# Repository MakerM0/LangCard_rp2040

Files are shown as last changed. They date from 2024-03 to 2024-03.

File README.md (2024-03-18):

# LangCard_rp2040

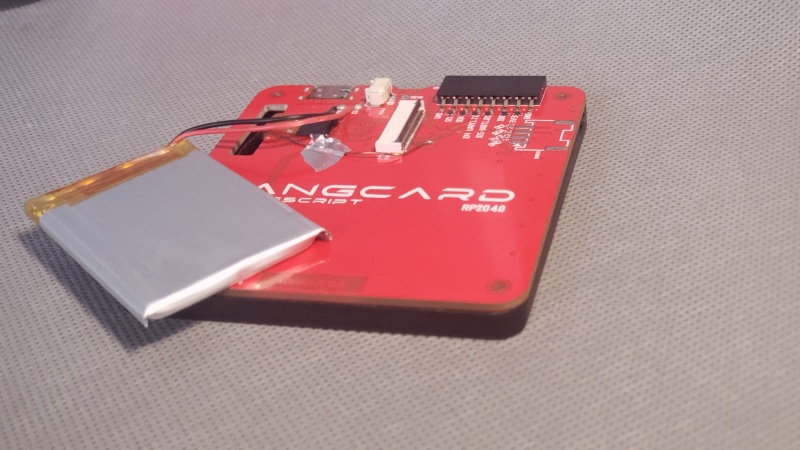
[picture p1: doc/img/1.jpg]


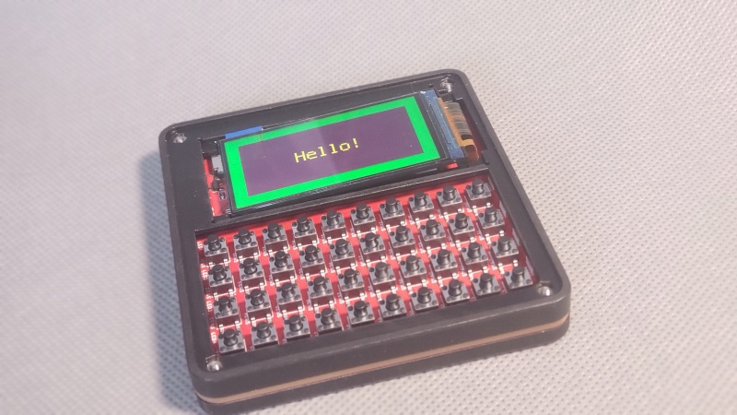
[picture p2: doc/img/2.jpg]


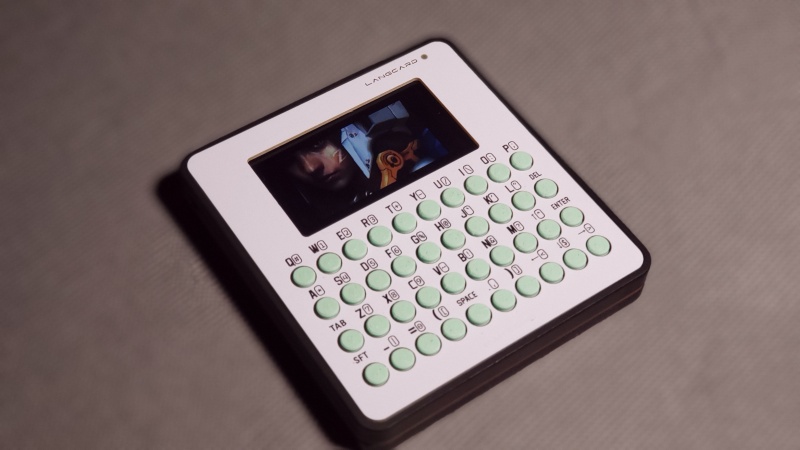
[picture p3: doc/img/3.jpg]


# PCB

The panel is made in the form of a PCB with a thickness of 1.0mm.

The thickness of the motherboard is 1.6mm, and the latest version is  Ver1.2.

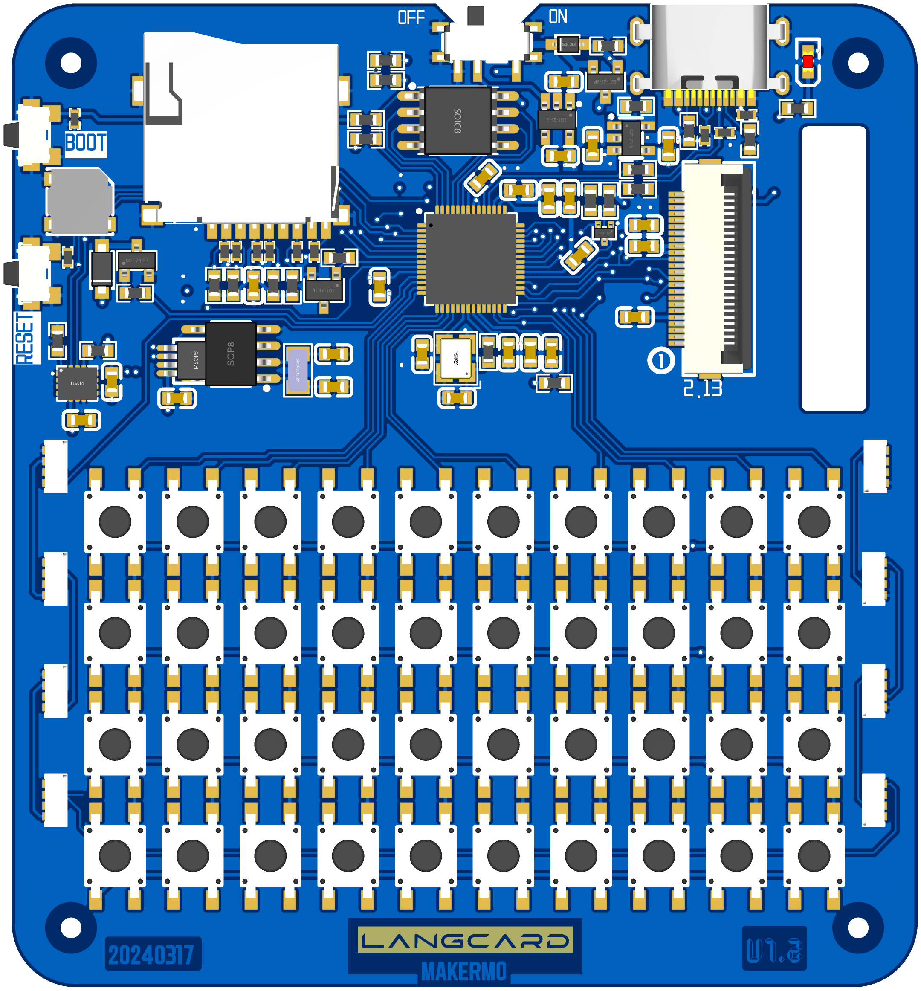
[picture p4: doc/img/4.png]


# Thanks

The [PCBway](https://pcbway.com/g/9CosjL) sponsored the project.

The demos is from:

- [github.com/Bodmer/TFT_eSPI](https://github.com/Bodmer/TFT_eSPI)
- [github.com/lvgl/lvgl](https://github.com/lvgl/lvgl)

- [github.com/VolosR](https://github.com/VolosR)
- [CircuitPython](https://circuitpython.org/)

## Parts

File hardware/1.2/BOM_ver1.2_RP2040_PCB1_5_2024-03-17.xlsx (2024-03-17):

Comment | Designator | Footprint | Supplier Part | Quantity
SMD-5025-0340-12Ω | BUZZER4 | BUZ-SMD_3P-L5.0-W5.0-BL | C2693575 | 1
12pF | C1,C6 | C0603 | C38523 | 2
10uF | C2,C5,C51 | C0603 | C19702 | 3
1uF | C3,C8,C208,C209,C210,C211,C212,C213,C214,C215 | C0603 | C15849 | 10
100nF | C4,C7,C9,C10,C11,C12,C13,C52,C53 | C0603 | C14663 | 9
100nF | C27 | C0603 | C1591 | 1
6pF | C49,C50 | C0603 | C37474 | 2
10uF | C216,C217 | c0603 | C19702 | 2
TF-01A | CARD1 | TF-SMD_TF-02 | C2889258 | 1
1N4148W | D3 | SOD-123F_L2.7-W1.6-LS3.8-RD | C81598 | 1
1N5819WS | D4 | sod-323_l1.8-w1.3-ls2.5-rd | C191023 | 1
PESDNC2FD3V3B | D9,D11,D12,D13,D14,D15,D16,D17,D18,D19,D20,D21,D22,D23,D25 | DFN1006-2L-BI | C492728 | 15
PESDNC2FD5VB | D10 | DFN1006-2L-BI | C110694 | 1
2.13寸电子水墨屏 | FPC2 | FPC-SMD_P0.50-24P_FGS-XJ-H2.0 |  | 1
AFC42-S12FMA-1H | FPC4 | CONN-SMD_12P-P0.50_L3.1-W8.0 | C466532 | 1
1.25-2PWB | FPC6 | CONN-SMD_2P-P1.25_DEALON_1.25-2PWB | C2905009 | 1
XL-4020RGBC-WS2812B | LED1,LED2,LED3,LED4,LED6,LED7,LED8,LED9 | LED-SMD_4P-L4.0-W1.7_M4020-03003-RGB-862-001 | C3647024 | 8
19-217/R6C-AL1M2VY/6T | LED5 | LED0603-R-FD | C2986060 | 1
BSS138 | Q1 | SOT-23-3_L2.9-W1.6-P1.90-LS2.8-BR | C112239 | 1
SS8050 | Q202 | SOT-23-3_L2.9-W1.3-P1.90-LS2.4-BR | C2150 | 1
AO3415 | Q203 | sot-23-3_l2.9-w1.3-p1.90-ls2.4-br | C181094 | 1
DMG1012T-7 | Q204 | SOT-523-3_L1.6-W0.8-P1.00-LS1.6-BR | C20512 | 1
10kΩ | R1,R7,R9,R28,R29,R30,R31,R54,R55,R220,R221 | R0603 | C25804 | 11
27Ω | R4,R8 | R0603 | C25190 | 2
1kΩ | R5,R16,R22,R214,R215 | R0603 | C21190 | 5
100kΩ | R13,R224 | R0603 | C25803 | 2
5.1kΩ | R207,R208 | R0603 | C23186 | 2
10Ω | R216,R217,R218,R219 | R0603 | C22859 | 4
200kΩ | R223 | R0603 | C25811 | 1
TS4550TP | SW11,SW12,SW13,SW14,SW15,SW16,SW17,SW18,SW19,SW20,SW22,SW23,SW24,SW25,SW26,SW27,SW28,SW29,SW30,SW31,SW33,SW34,SW35,SW36,SW37,SW38,SW39,SW40,SW41,SW42,SW44,SW45,SW46,SW47,SW48,SW49,SW50,SW51,SW52,SW53 | SW-SMD_4P-L4.5-W4.5-P3.00-LS7.0 | C412373 | 40
MSK12C02 | SW110 | SW-TH_MSK12C02 | C431540 | 1
TS24CA | SW111,SW112 | SW-SMD_TS24CA | C393942 | 2
FPC-05FB-30PH20 | TFT1 | FPC-SMD_30P-P0.50_FPC-05FB-30PH20 | C2856833 | 1
TP4054-42-SOT25R | U1 | sot-23-5_l3.0-w1.7-p0.95-ls2.8-br | C32574 | 1
RP2040 | U2 | LQFN-56_L7.0-W7.0-P0.4-EP | C2040 | 1
W25Q128JVSIQ | U3 | SOIC-8_L5.3-W5.3-P1.27-LS8.0-BL | C97521 | 1
AP2112K-3.3TRG1 | U6 | SOT-25-5_L3.0-W1.8-P0.95-LS3.0-BR | C51118 | 1
LSM6DS3TR-C | U26 | LGA-14_L3.0-W2.5-P0.50-TL | C967633 | 1
BM8563ESA | U207 | SOP-8_L5.0-W4.0-P1.27-LS6.0-BL | C269877 | 1
X6511FRS-08-C85D30 | U211 | HDR-SMD_8P-P2.54-H-F-L11.5 | C5142241 | 1
{ManufacturerPart!} | USB4 | USB-C-SMD_SHOU_TYPE-C-16P-CB1.6 | C2906290 | 1
12MHz | X1 | OSC-SMD_4P-L3.2-W2.5-BL | C9002 | 1
32.768kHz | X3 | OSC-SMD_L3.2-W1.5 | C94673 | 1

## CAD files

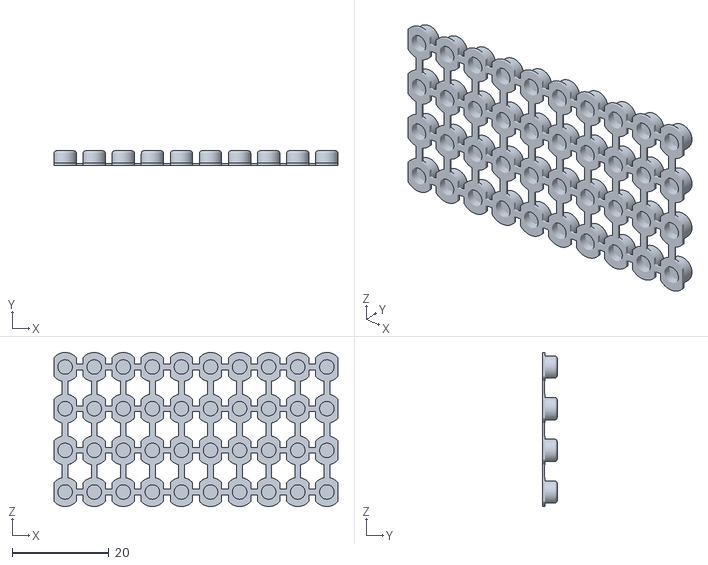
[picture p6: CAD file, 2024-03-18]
mechanical/button.stl
58.6 x 3.00 x 31.8

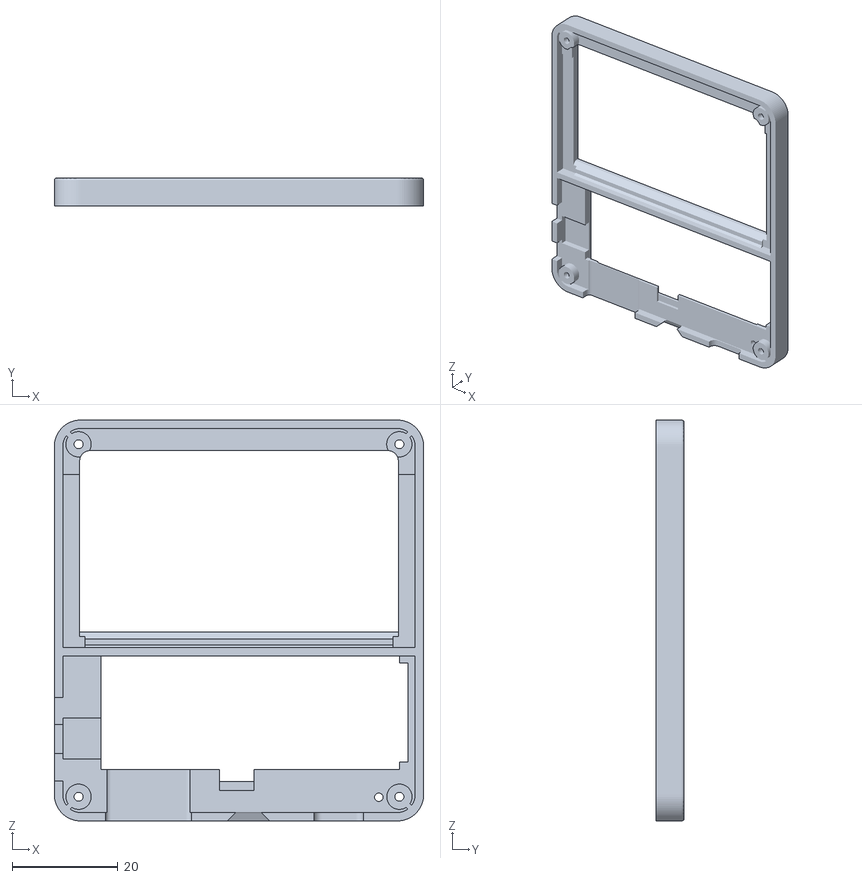
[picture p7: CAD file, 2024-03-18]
mechanical/top.stl
70.0 x 5.40 x 76.0

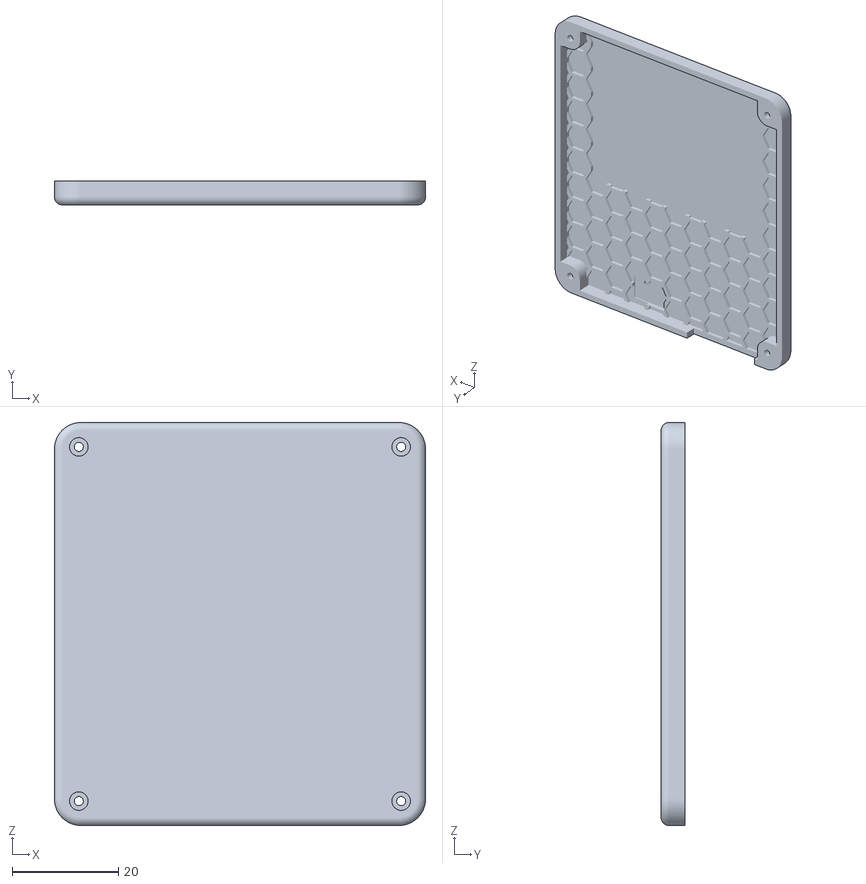
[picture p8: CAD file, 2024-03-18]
mechanical/bot.stl
70.0 x 4.50 x 76.0

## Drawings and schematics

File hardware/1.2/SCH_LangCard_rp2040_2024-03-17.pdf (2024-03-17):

## GND

## GND CC1

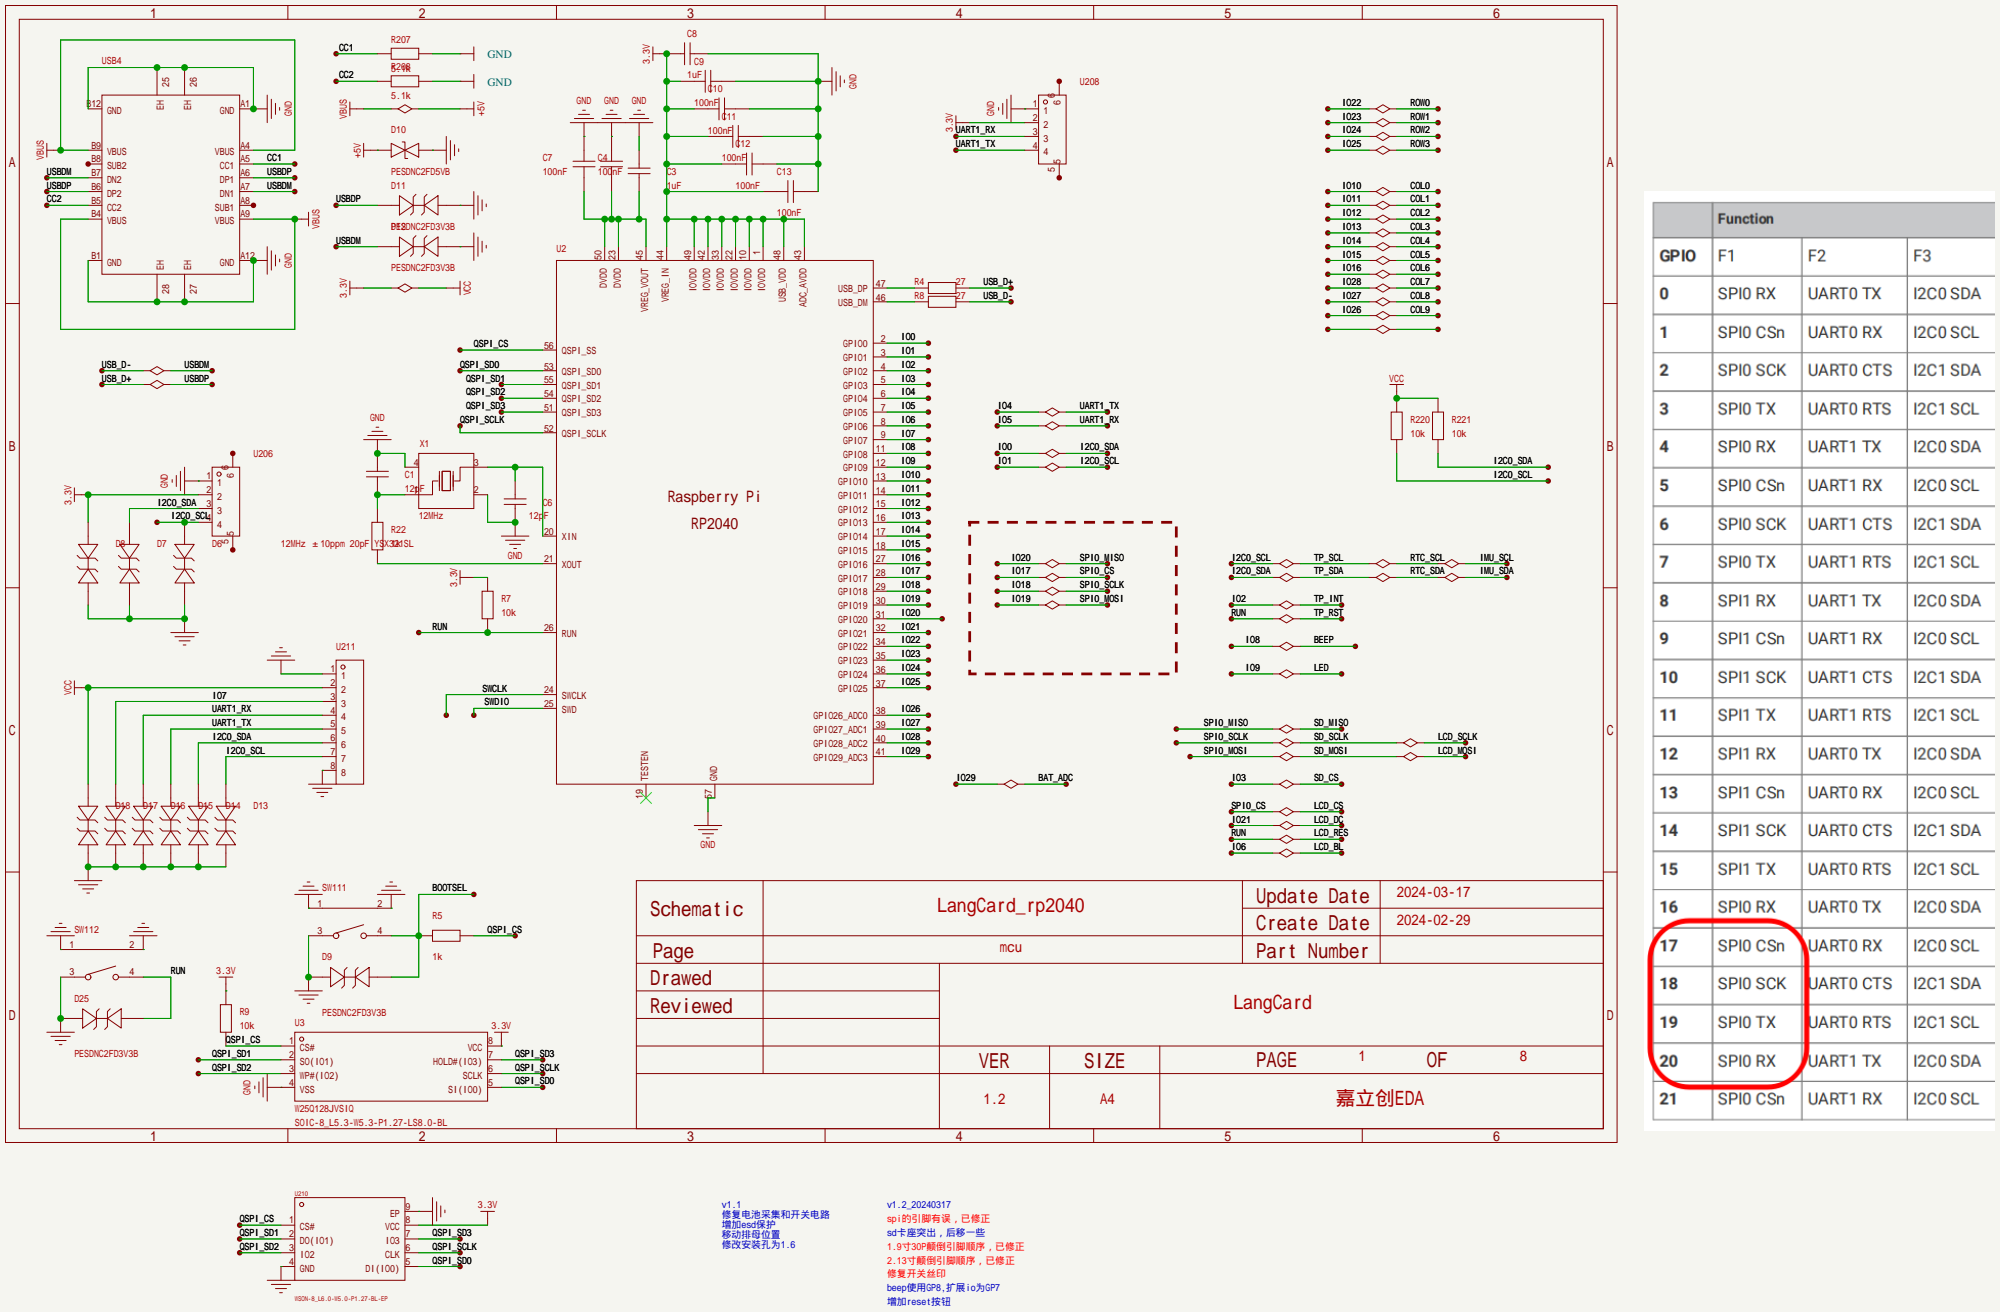
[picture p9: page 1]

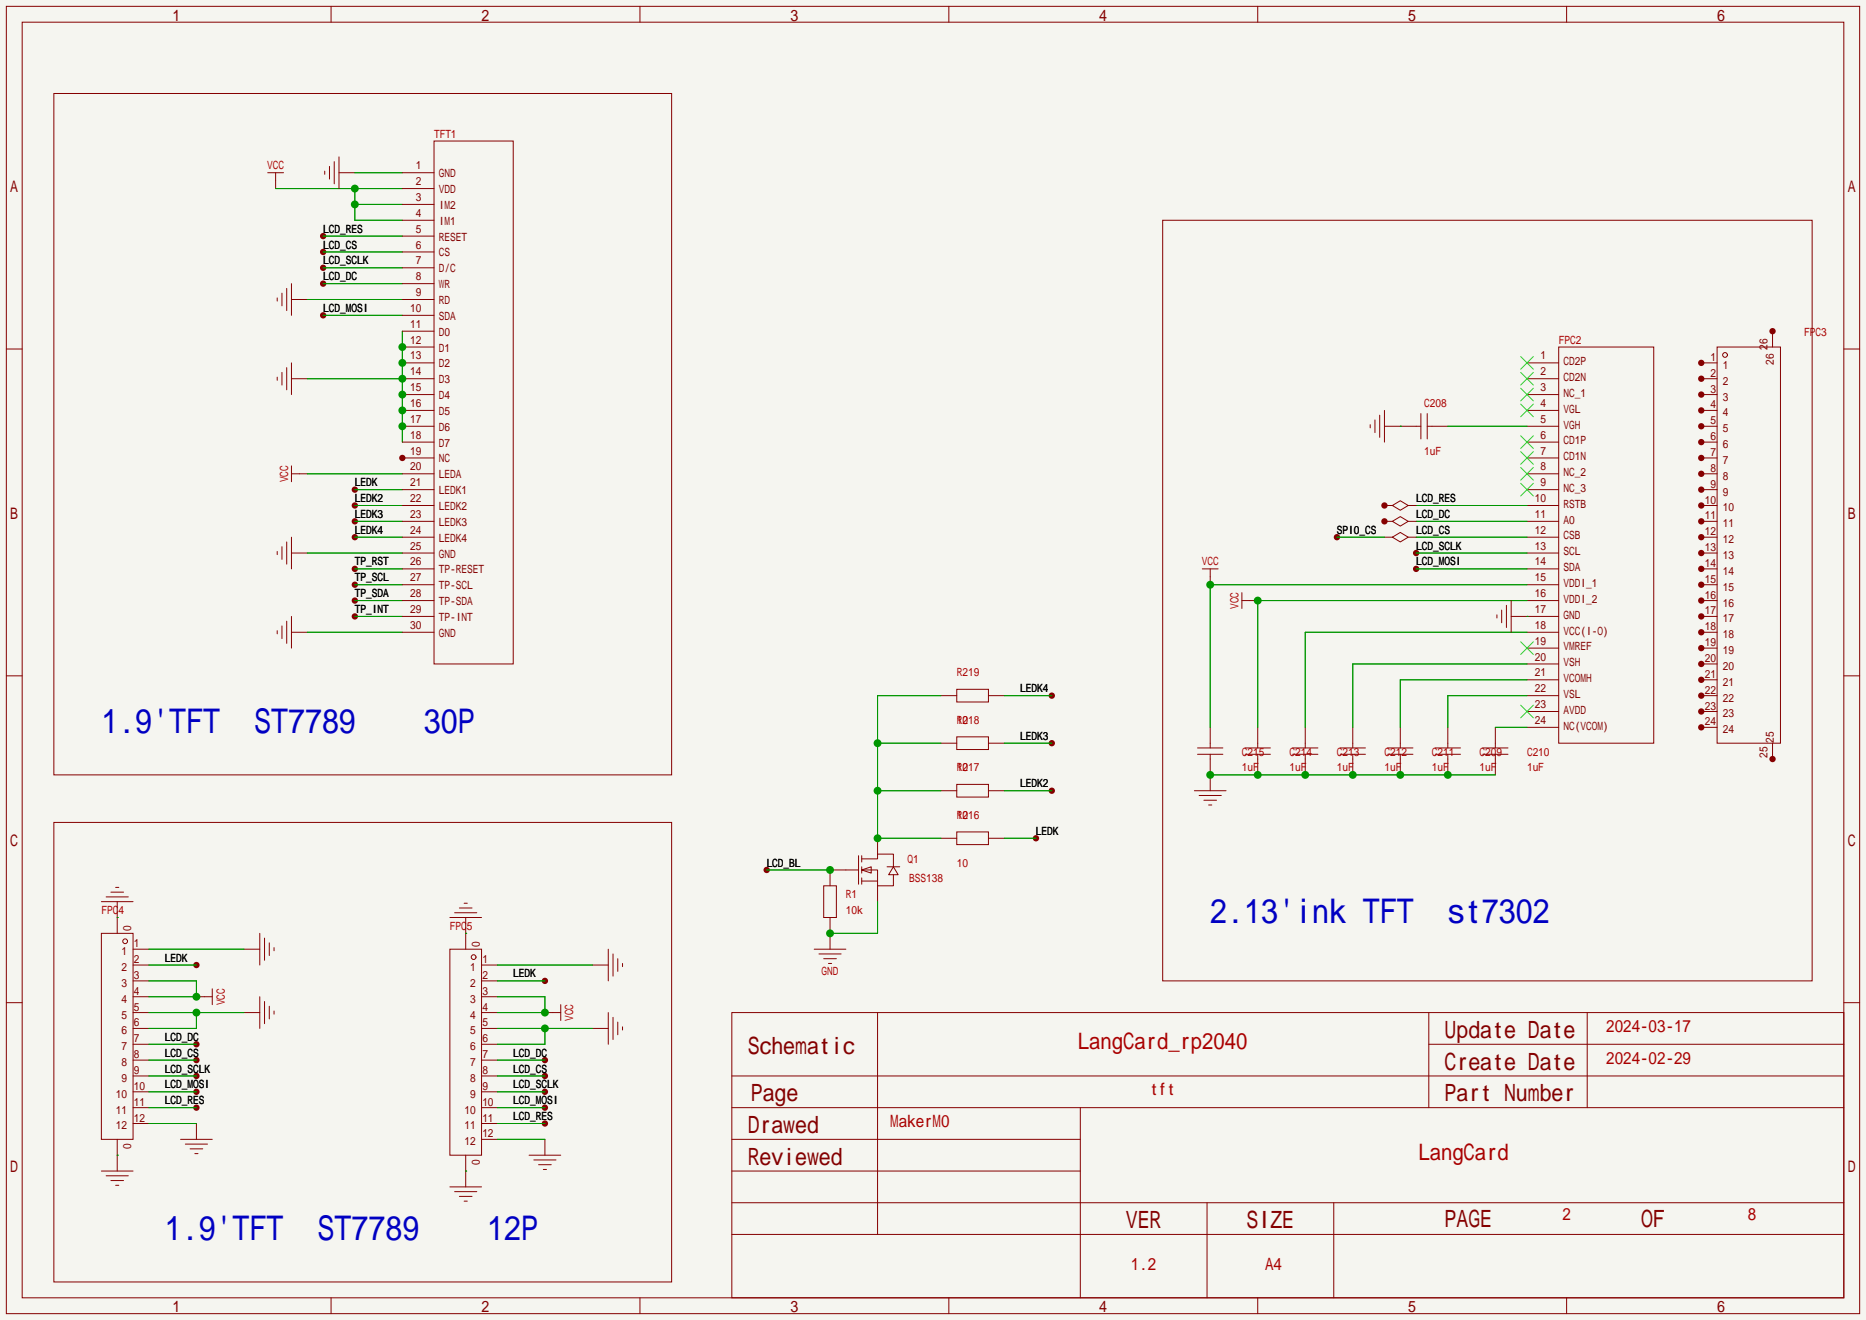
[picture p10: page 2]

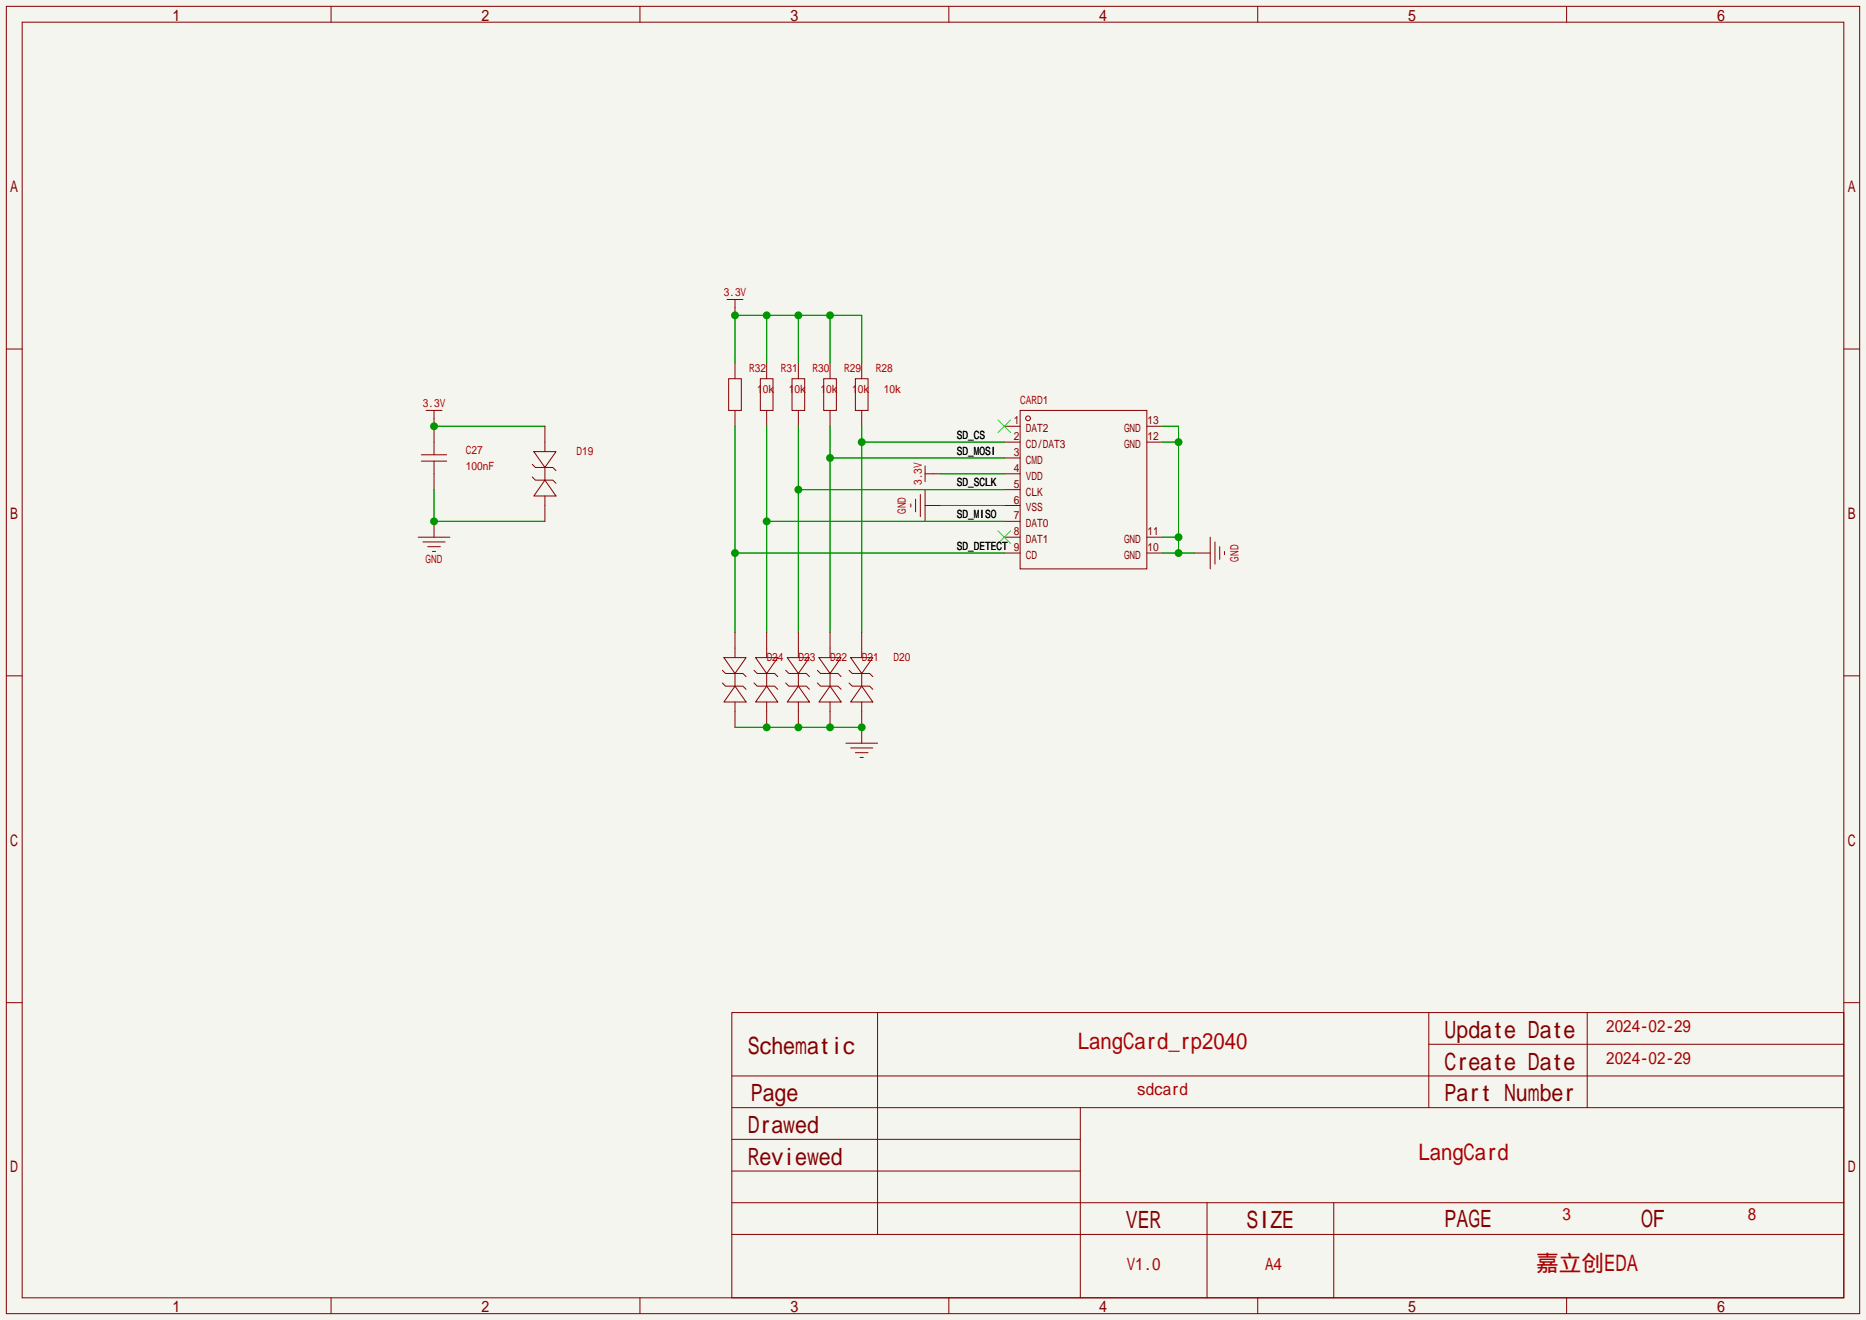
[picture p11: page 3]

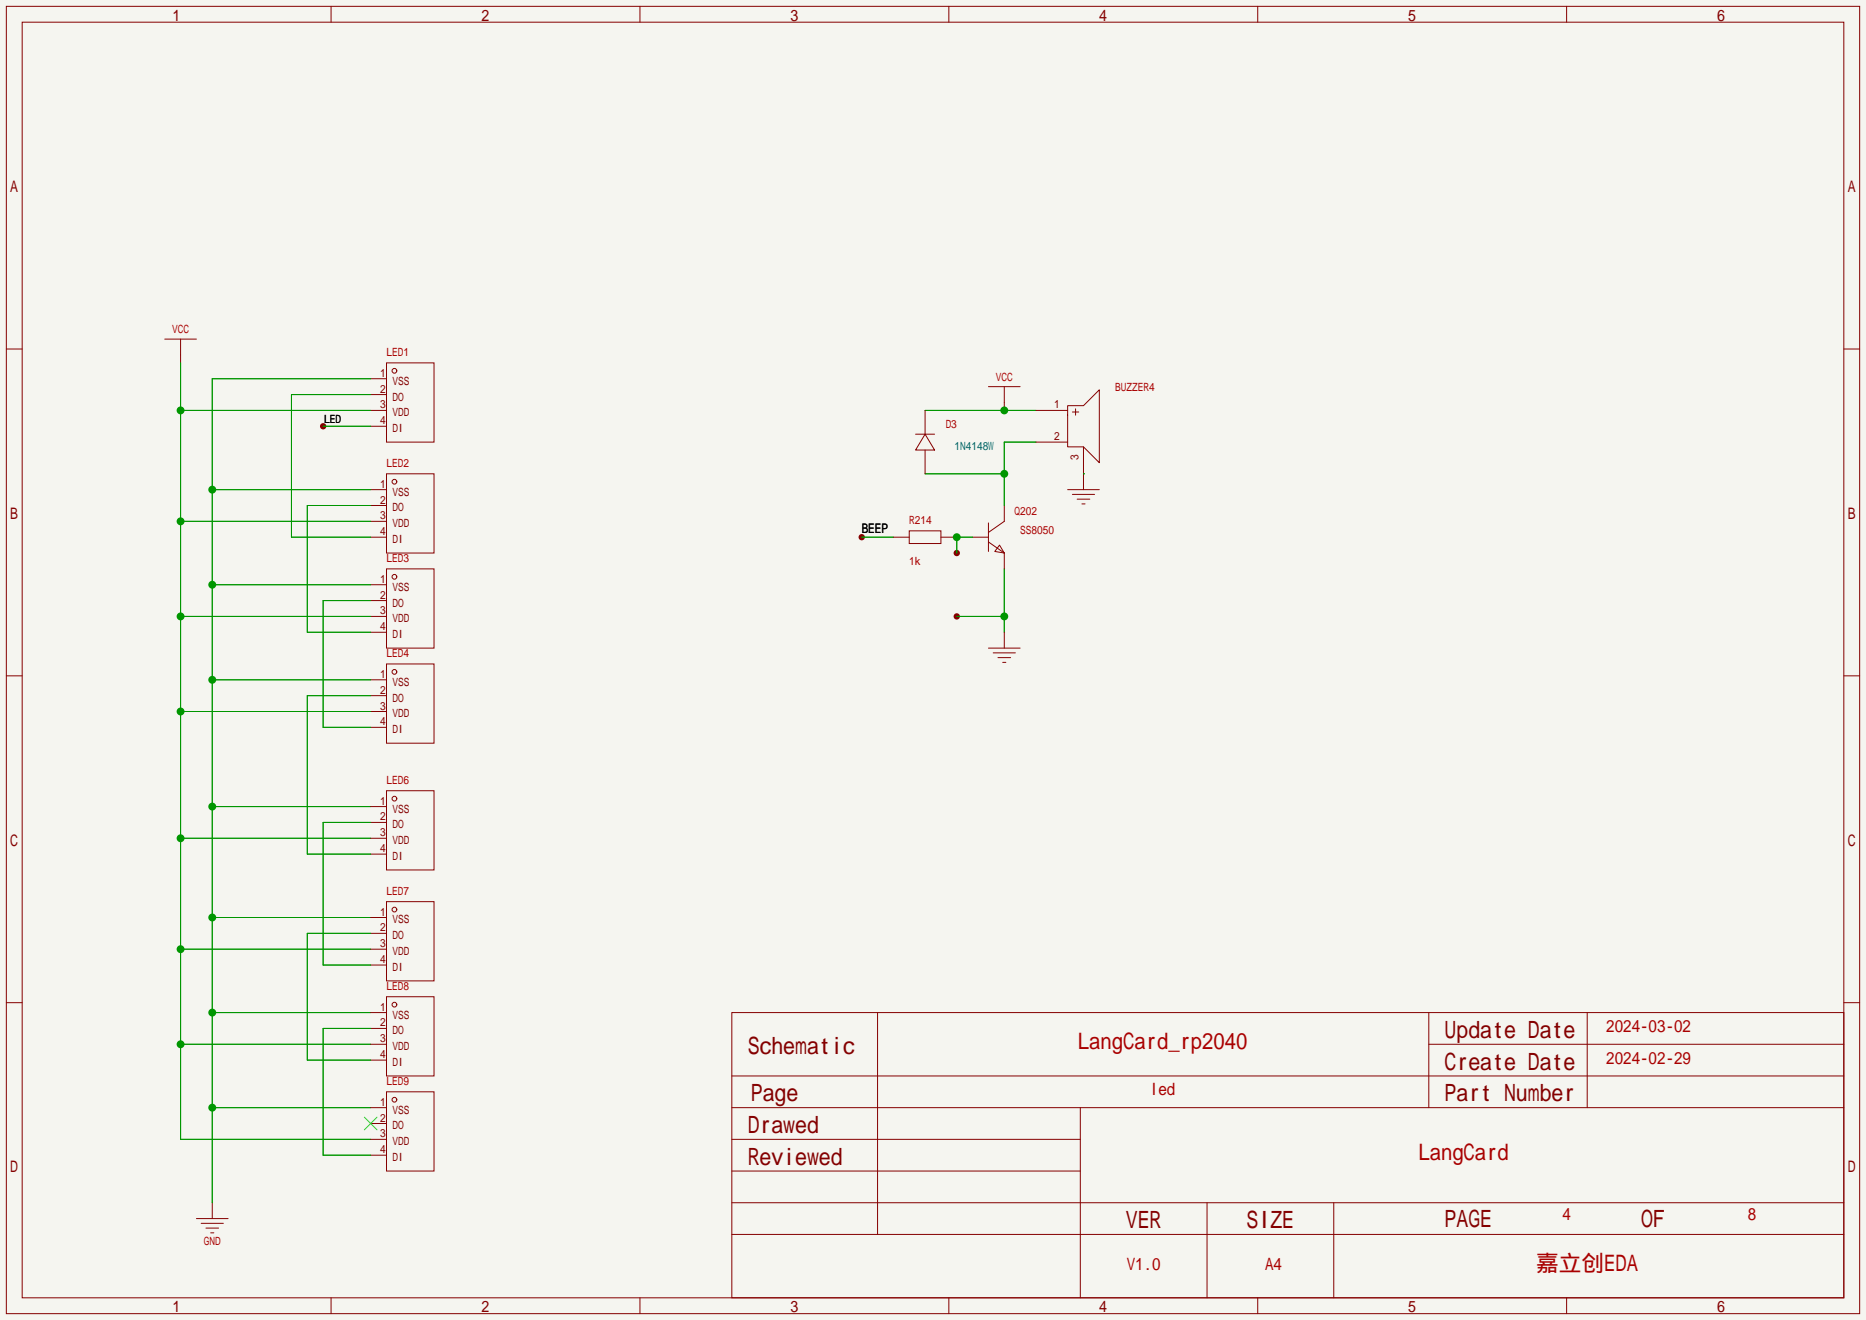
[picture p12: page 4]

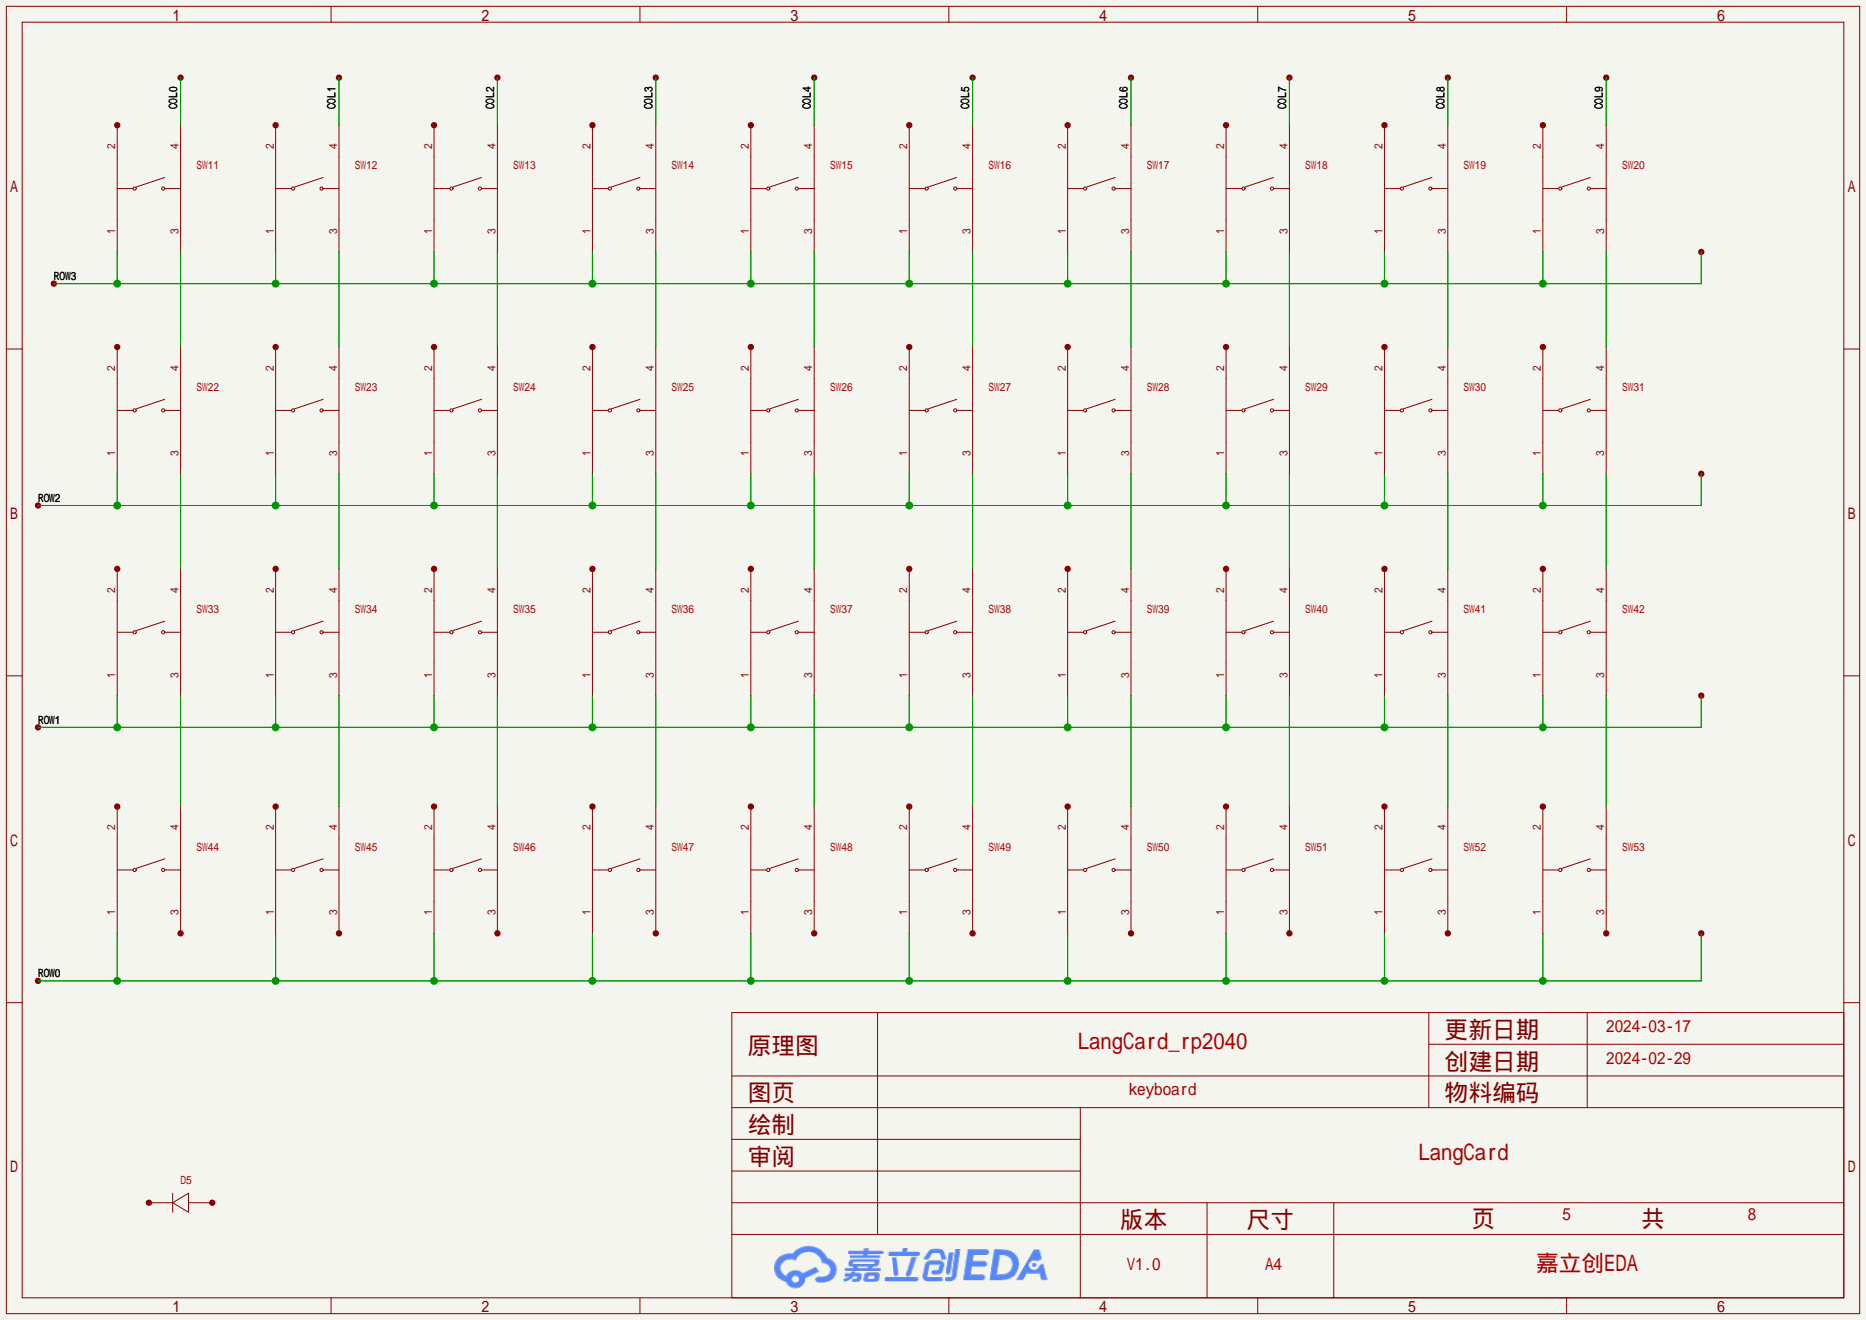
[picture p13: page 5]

## VBAT

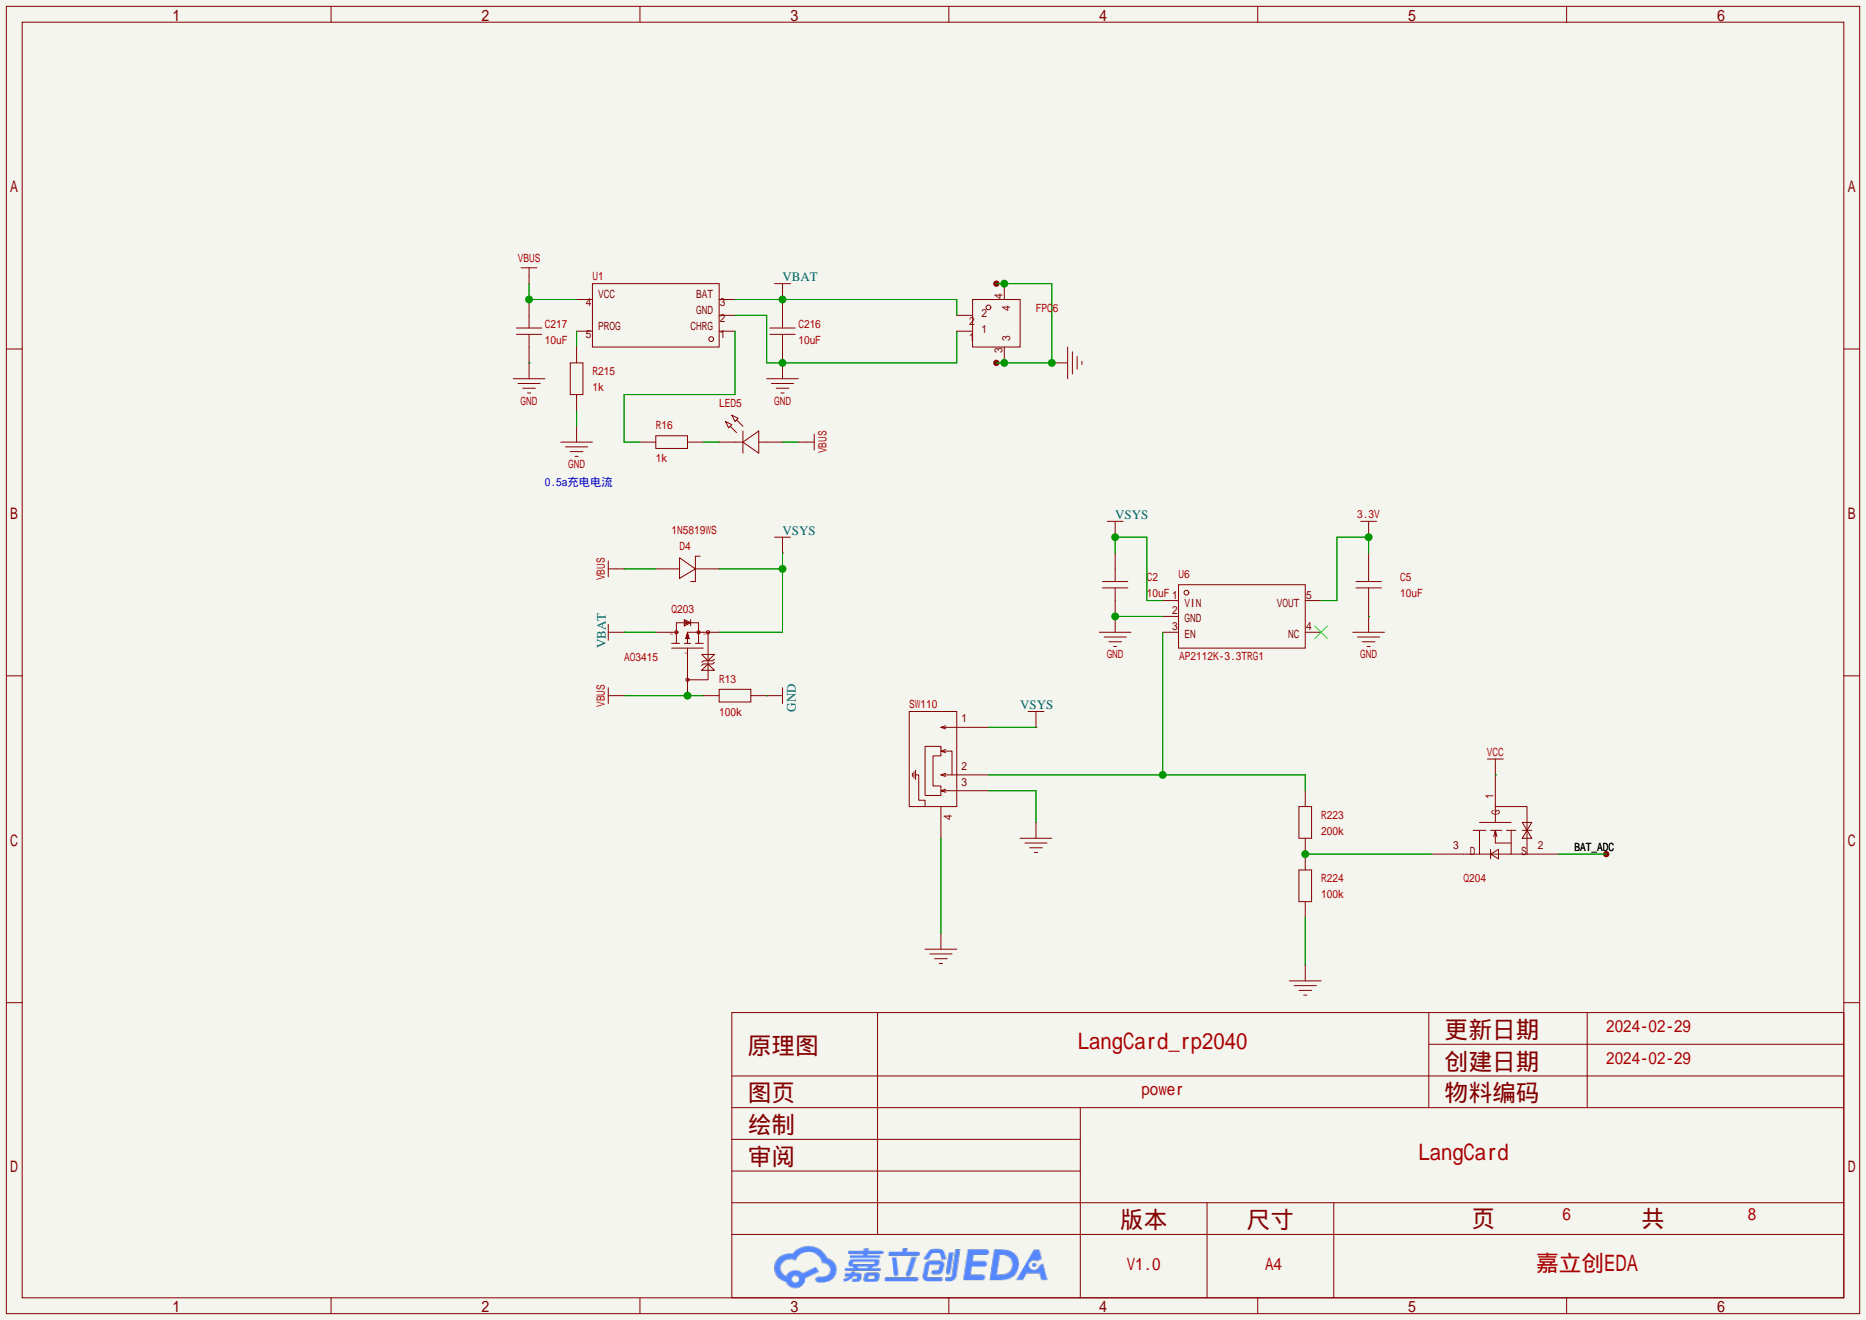
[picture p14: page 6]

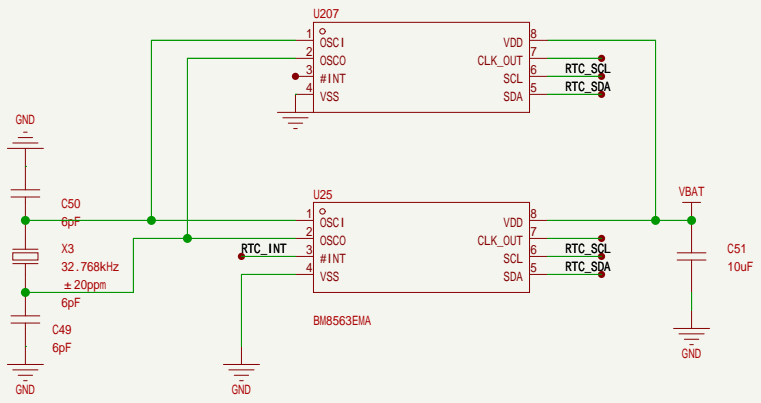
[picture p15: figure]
OSCI OSCO #INT; VSS; SDA; SCL; CLK_OUT; VDD; BM8563EMA; X3 32.768kHz ±20ppm 6pF; GND; RTC_SCL RTC_SDA; VBAT; RTC_INT

审阅

绘制

# 创建日期 物料编码

页 | 共
原理图 | 更新日期

图页

| LangCard

2024-02-29

2024-02-29

# LangCard_rp2040

## RTC

注：1. 如使用负载电容为6pF的32.768KHz晶振，则需在OSCI、OSCO脚连接约6pF匹配电容用以调节初始精度。
2. 如使用负载电容为12.5pF的32.768KHz晶振，则需在OSCI、OSCO脚连接约19pF匹配电容用以调节初始精度。
3. 如果VCC电源线上有噪声或者干扰信号发生，建议在电源线上增加电阻、电容进行过滤。

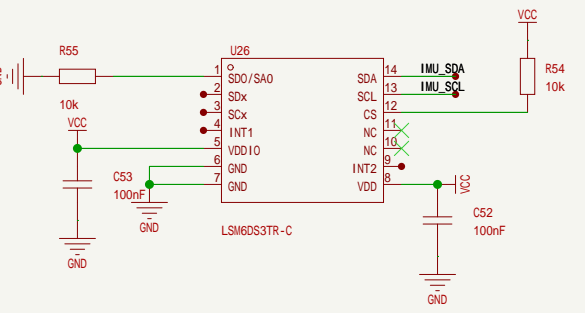
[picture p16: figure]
SDO/SA0 SDx SCx INT1 VDDIO GND; GND; VDD; INT2; SCL; SDA; LSM6DS3TR-C; VCC; IMU_SDA IMU_SCL

审阅

绘制

# 创建日期 物料编码 页

共

原理图 | 更新日期

图页

| LangCard

2024-02-29

2024-02-29

# LangCard_rp2040

## IMU

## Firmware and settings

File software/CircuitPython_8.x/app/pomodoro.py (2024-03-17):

'''
pomodoro.py
v0.2.0
    20230725
    modify playwave
    
v0.1.0
    20230723
    first release
    
'''




from langcard import *
from adafruit_display_text import label
import array
import math
import time
import audiocore
import audiobusio 
from adafruit_progressbar.horizontalprogressbar import (
    HorizontalProgressBar,
    HorizontalFillDirection,
)


WORK = 25
SHORTBREAK = 5
COLOR_STOPED = 0xff0000
COLOR_STARTED = 0x00ff00

# Generate one period of sine wav, 8ksps 440 Hz sin wave:
length = 8000 // 440
sine_wave = array.array("h", [0] * length)
for i in range(length):
    sine_wave[i] = int(math.sin(math.pi * 2 * i / length) * (2 ** 15))
sine_wave = audiocore.RawSample(sine_wave)

def playwave(filename):
#     audiopwr_on()
#     i2s = audiobusio.I2SOut(AUDIO_BCK,AUDIO_WS,AUDIO_DATA)
#     try :
#         wave_file = open('audio/pomodoro/{}'.format(filename), "rb")
#         wave = audiocore.WaveFile(wave_file)
#         i2s.play(wave)
#         while i2s.playing:
#             pass
#         wave.deinit()
#         wave_file.close()
#         wave_file=None
#         gc.collect()
#          
#     except Exception as e : 
#         print (e)
#     i2s.deinit()
#     audiopwr_off()
    pass



# Define the Pomodoro class
class Pomodoro:
    def __init__(self,worktime:int,shortbreaktime:int):
        self.workmode=0
        self.shortbreakmode=1
        
        self.worktime = worktime
        self.shortbreaktime = shortbreaktime
        
        self.time=self.worktime
        self.mode= self.workmode
        self.minutes = self.worktime
        self.seconds = 0
        self.is_running = False

    def display_time(self):
        # Calculate the remaining time in minutes and seconds
        remaining_minutes = self.minutes
        remaining_seconds = self.seconds

        # Display the remaining time
        print(f"Time remaining: {remaining_minutes:02d}:{remaining_seconds:02d}")
    def setmode(self,mode):
        if mode==self.workmode:            
            self.time = self.worktime
        elif mode==self.shortbreakmode:
            self.time = self.shortbreaktime
        self.mode = mode
        
        
    def getmode(self):
        return self.mode
        
        
    def reset(self):
        # Reset the timer to the default values
        self.minutes = self.time 
        self.seconds = 0
        self.is_running = False

    def start(self):
        # Start the timer
        self.is_running = True

    def pause(self):
        # Pause the timer
        self.is_running = False

    def toggle(self):
        # Toggle the timer between running and paused
        self.is_running = not self.is_running
        

# Create an instance of the Pomodoro class
pomodoro = Pomodoro(WORK,SHORTBREAK)


display.show(None)
main_group = displayio.Group()

# label
t_label = label.Label(terminalio.FONT, color=COLOR_STARTED, scale=4)
t_label.anchor_point = (0.5, 0.0)
t_label.anchored_position = (display.width / 2, 40)
t_label.text = f"{WORK:02d}:{00:02d}"

mode_label = label.Label(terminalio.FONT, color=0xB4D7FA, scale=2)
mode_label.anchor_point = (0.5, 0.0)
mode_label.anchored_position = (display.width / 2, 10)
mode_label.text = "Pomodoro" 

main_group.append(t_label)
main_group.append(mode_label) 


# set progress bar width and height relative to board's display
width = display.width - 10
height = 15

x = display.width // 2 - width // 2
y = display.height // 2+30

# Create a new progress_bar object at (x, y)
progress_bar = HorizontalProgressBar(
    (x, y), (width, height), direction=HorizontalFillDirection.LEFT_TO_RIGHT
)

# Append progress_bar to the splash group
main_group.append(progress_bar)
display.show(main_group)
playwave('go.wav')

t_old=0
# Main loop to update and display the timer
while True:
    if (time.monotonic()-t_old) >= 1.0:
        t_old = time.monotonic()
        if pomodoro.is_running:
        # Decrease the timer by 1 second
            if pomodoro.seconds > 0:
                pomodoro.seconds -= 1
            elif pomodoro.minutes > 0:
                pomodoro.minutes -= 1
                pomodoro.seconds = 59
            else:
                mode = pomodoro.getmode()
                if mode==pomodoro.workmode:
                    pomodoro.setmode(pomodoro.shortbreakmode)
                    mode_label.text = "Break" 
                    t_label.color = COLOR_STOPED
                elif mode==pomodoro.shortbreakmode:
                    pomodoro.setmode(pomodoro.workmode)
                    mode_label.text = "Pomodoro" 
                    t_label.color = COLOR_STOPED
                # Timer has reached 0, reset the timer
                pomodoro.reset()
                mode = pomodoro.getmode()
                if mode == pomodoro.workmode:
                    playwave('go.wav')
                elif mode==pomodoro.shortbreakmode:
                    playwave('break.wav')
            # Display the timer
            pomodoro.display_time()
            t_label.text = f"{pomodoro.minutes:02d}:{pomodoro.seconds:02d}"
            progress_bar.value = int((1- ((pomodoro.minutes*60+pomodoro.seconds)/(pomodoro.time*60) ))*(progress_bar.maximum - progress_bar.minimum))
    

    
    key = getkey()
    if key==KEY_ENTER:
        if not pomodoro.is_running:
            t_label.color = COLOR_STARTED
            pomodoro.start()
            t_old = time.monotonic()
        else:
            t_label.color = COLOR_STOPED
            pomodoro.pause()
    if key=='p'  :
         
        mode = pomodoro.getmode()
        if mode==pomodoro.workmode:
            pomodoro.setmode(pomodoro.shortbreakmode)
            mode_label.text = "Break" 
        elif mode==pomodoro.shortbreakmode:
            pomodoro.setmode(pomodoro.workmode)
            mode_label.text = "Pomodoro" 
        pomodoro.reset()
        t_label.color = COLOR_STARTED
        t_label.text = f"{pomodoro.minutes:02d}:{pomodoro.seconds:02d}"
        progress_bar.value = progress_bar.minimum
            
                
            
    # Wait for 1 second
    time.sleep(0.1)
    
    if key=='q'  :      
        returnMainPage()
    
    

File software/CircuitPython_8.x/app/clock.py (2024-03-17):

# SPDX-FileCopyrightText: 2019 Sommersoft
# SPDX-FileCopyrightText: Copyright (c) 2021 Jeff Epler for Adafruit Industries
#
# SPDX-License-Identifier: Unlicense

# Simple demo of reading and writing the time for the PCF8563 real-time clock.
# Change the if False to if True below to set the time, otherwise it will just
# print the current date and time every second.  Notice also comments to adjust
# for working with hardware vs. software I2C.

import time
import board
import busio
from langcard import *
from adafruit_display_text import label

from adafruit_pcf8563.pcf8563 import PCF8563

WEEK_COLOR_NOW = 0xCCCCCC
WEEK_COLOR_NOTNOW=0x444444
CALENDAR_COLOR = 0xCCCCCC

# Change to the appropriate I2C clock & data pins here!
# i2c = busio.I2C(board.GP1, board.GP0)

# Create the RTC instance:
rtc = PCF8563(i2c)

# Lookup table for names of days (nicer printing).
days = ("Monday", "Tuesday", "Wednesday", "Thursday", "Friday", "Saturday", "Sunday")


# pylint: disable-msg=using-constant-test
if False:  # change to True if you want to set the time!
    #                     year, mon, date, hour, min, sec, wday, yday, isdst
    t = time.struct_time((2024, 3, 17, 14, 9, 0, 6, -1, -1))
    # you must set year, mon, date, hour, min, sec and weekday
    # yearday is not supported, isdst can be set but we don't do anything with it at this time
    print("Setting time to:", t)  # uncomment for debugging
    rtc.datetime = t
    print()
# pylint: enable-msg=using-constant-test



display.show(None)
main_group = displayio.Group()

from adafruit_bitmap_font import bitmap_font
font_file = "fonts/LeagueSpartan-Bold-16.bdf"
font = bitmap_font.load_font(font_file)
# font = terminalio.FONT
time_now = rtc.datetime
# label

colon_label = label.Label(terminalio.FONT, color=0xffffff, scale=6)
colon_label.anchor_point = (0.0, 0.0)
colon_label.anchored_position = (160, 30)
colon_label.text = ":"


hour_label = label.Label(terminalio.FONT, color=0x00ff00, scale=8)
hour_label.anchor_point = (0.0, 0.0)
hour_label.anchored_position = (60, 20)
hour_label.text = "{:0>2d}".format(time_now.tm_hour)

minute_label = label.Label(terminalio.FONT, color=0x00ffff, scale=8)
minute_label.anchor_point = (0.0, 0.0)
minute_label.anchored_position = (200, 20)
minute_label.text ="{:0>2d}".format(time_now.tm_min)


calendar_label = label.Label(terminalio.FONT, color=CALENDAR_COLOR, scale=2)
calendar_label.anchor_point = (0.0, 0.0)
calendar_label.anchored_position = (160, 140)
calendar_label.text = "{}-{}-{}".format(time_now.tm_year, time_now.tm_mon, time_now.tm_mday)

# gc_label = label.Label(terminalio.FONT, color=0xff00ff, scale=1)
# gc_label.anchor_point = (0.5, 0.0)
# gc_label.anchored_position = (display.width / 2+40, 110)
# gc_label.text = "{}KB".format(gc.mem_free()/1024)


main_group.append(colon_label)
main_group.append(hour_label)
main_group.append(minute_label)
main_group.append(calendar_label)
# main_group.append(gc_label)


week_id = time_now.tm_wday
week_label=[]
weeks = ("MON","TUE","WED","THU","FRI","SAT","SUN")
for i in range(7):
    wlabel = label.Label(font, color=WEEK_COLOR_NOTNOW, scale=1)
    wlabel.anchor_point = (0.0, 0.0)
    wlabel.anchored_position = (0, i*25)
    wlabel.text = f"{weeks[i]}"
    week_label.append(wlabel)
    main_group.append(wlabel)
    
week_label[week_id].color = WEEK_COLOR_NOW


display.show(main_group)



now =  time.monotonic()
old=now
# Main loop:
while True:
    
    now =  time.monotonic()
    if (now-old) >= 1.0:
        old = now  
 
        if rtc.datetime_compromised:
            print("RTC unset")
        else:
            print("RTC reports time is valid")
        t = rtc.datetime
        # print(t)     # uncomment for debugging
        print(
            "The date is {} {}/{}/{}".format(
                days[int(t.tm_wday)], t.tm_mday, t.tm_mon, t.tm_year
            )
        )
        print("The time is {}:{:02}:{:02}".format(t.tm_hour, t.tm_min, t.tm_sec))
        time.sleep(1)  # wait a second
        
        colon_label.color = 0xffffff - colon_label.color
        hour_label.text = "{:0>2d}".format(t.tm_hour)
        minute_label.text = "{:0>2d}".format(t.tm_min)
        calendar_label.text = "{}-{}-{}".format(t.tm_year, t.tm_mon, t.tm_mday)
    
    time.sleep(0.01)
    key = getkey()    
    if key:
        if key=='q':
            print('exit')
            returnMainPage()     
        else: 
            pass
   
    
    
